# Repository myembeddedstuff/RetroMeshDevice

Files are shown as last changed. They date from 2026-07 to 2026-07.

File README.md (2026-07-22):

# RetroMeshDevice 

An off-grid handheld communicator built for the **Meshtastic Build-Off 2026** hardware competition. 

The goal is to build a standalone device that runs Meshtastic natively, using an ESP32-S3 and a custom 12-button T9 physical keypad (driven by an MCP23017 I/O expander).

<p align="center">
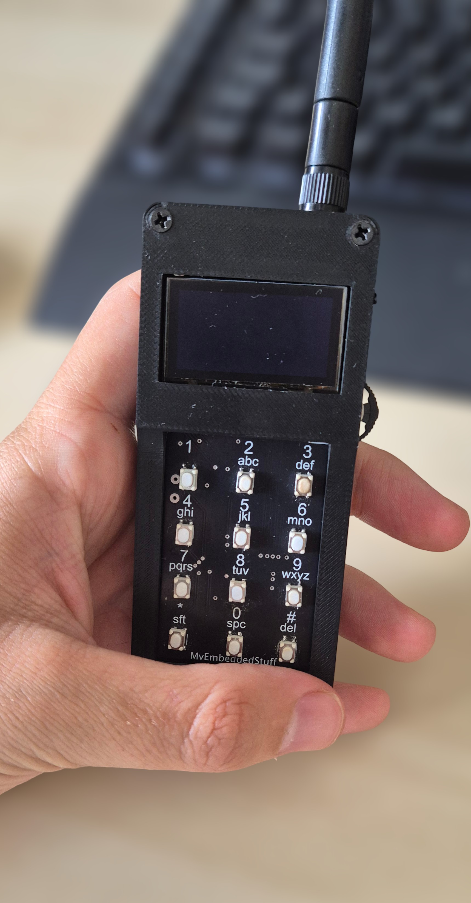
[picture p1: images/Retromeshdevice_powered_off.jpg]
  
</p>

---

## 📖 What this project does

RetroMeshDevice (RMD) is a custom-built, standalone Meshtastic node in a retro phone form factor. Unlike phone-paired setups, it's a self-contained device with its own screen, keypad, battery, and LoRa radio built from scratch around a T9 physical keypad instead of a touchscreen or QWERTY layout.

It's designed as an alternative for people who want a dedicated, pocketable Meshtastic node without depending on a smartphone to configure, send, or read messages
<p align="center">
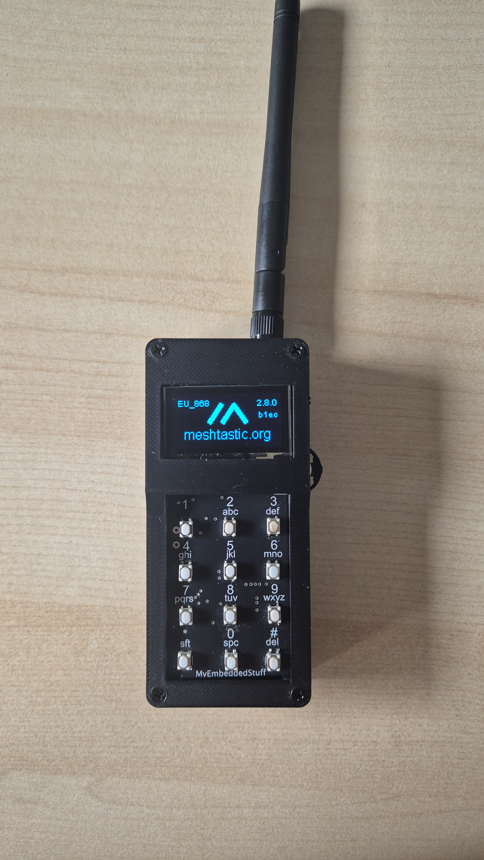
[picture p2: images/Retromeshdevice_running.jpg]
  
</p>

---
I am documenting the entire design and assembly process step-by-step on my blog:
* **Part 1 (Schematic & Design):** [myembeddedstuff.com/meshtastic-build-off-2026-retromeshdevice](https://myembeddedstuff.com/meshtastic-build-off-2026-retromeshdevice)
* **Part 2 (PCB Assembly):** [myembeddedstuff.com/meshtastic-build-off-2026-pcb-assembly](https://myembeddedstuff.com/meshtastic-build-off-2026-pcb-assembly)
* **Part 3 (Firmware Validation & Power Consumption):** [myembeddedstuff.com/meshtastic-build-off-2026-hardware-bring-up](https://myembeddedstuff.com/meshtastic-build-off-2026-hardware-bring-up)

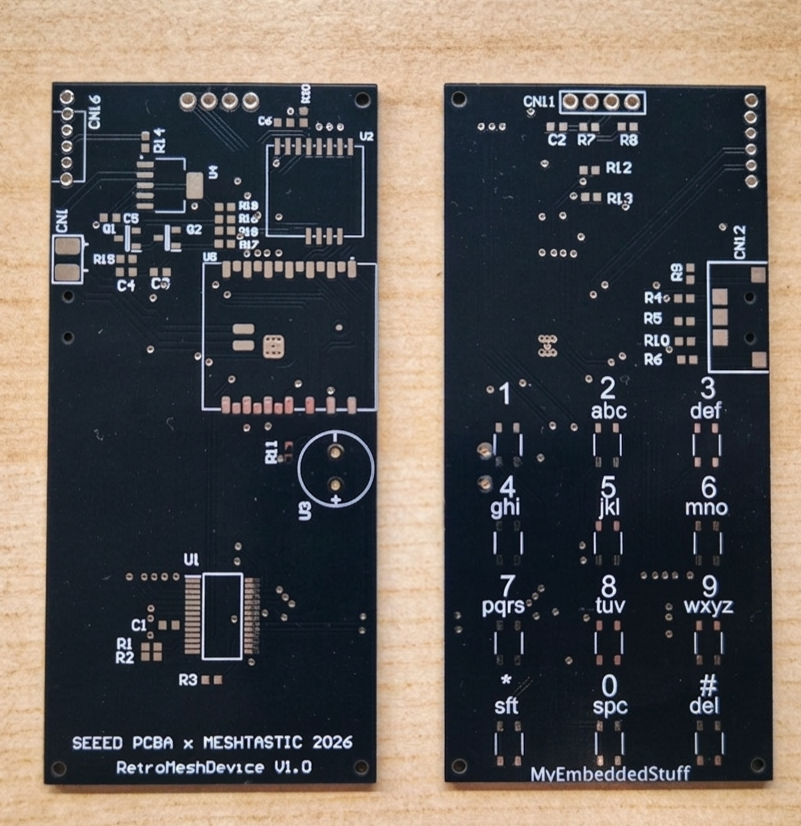
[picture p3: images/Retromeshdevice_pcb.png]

---

### 📂 Repository structure

* **`/case`** — 3D printable case STEP file.
* **`/hardware`** — Schematic diagrams and Bill of Materials (BOM).
* **`/firmware`** — Firmware source code and utilities:
  * **`/Meshtastic`** — Custom Meshtastic variant for this board, ready to compile.
  * **`/Test`** — Standalone hardware self-test firmware for quick board bring-up validation.
  * **`/Bin`** — Precompiled binary (Meshtastic v2.8).
* **`/images`** — Project photos and renders.

---

## 🔗 How it uses Meshtastic

RetroMeshDevice runs a **custom Meshtastic firmware variant** rather than stock Meshtastic, because out-of-the-box Meshtastic firmware doesn't support the MCP23017 I/O expander that drives this board's T9 keypad.

To make this work, I implemented a full MCP23017 keyboard driver for the Meshtastic firmware (interrupt handling, key debounce/multi-tap/long-press logic, I2C device detection) and submitted it upstream:

👉 [meshtastic/firmware PR #11015 — feat: add driver for MCP23017](https://github.com/meshtastic/firmware/pull/11015)

Until this PR is merged into the official Meshtastic repository, you'll need to apply these changes manually (see **Installation** below).

---

## 🚀 Installation & running

1. **Clone the official Meshtastic firmware repo:**
```bash
   git clone https://github.com/meshtastic/firmware.git
   cd firmware
```

2. **Add MCP23017 support:**
   - Check if [PR #11015](https://github.com/meshtastic/firmware/pull/11015) has already been merged into `develop`.
   - **If merged:** skip to step 3.
   - **If not merged yet:** copy over the modified files from that PR into your local clone (`src/detect/ScanI2C.*`, `src/detect/ScanI2CTwoWire.cpp`, `src/input/MCP23017Keyboard.*`, `src/input/cardKbI2cImpl.cpp`, `src/input/kbI2cBase.*`, `src/main.cpp`).

3. **Add the board variant:**
   - Copy the contents of this repo's [`/FW_Meshtastic`](FW_Meshtastic) folder into the corresponding `variants/` folder of your Meshtastic firmware clone.

4. **Build and flash:**
```bash
   pio run -e retroMeshDevice -t upload
```
   This compiles the firmware for the `retroMeshDevice` environment and uploads it directly if the board is connected via USB.

5. **Alternative — use the precompiled binary:**
   - If you don't want to build it yourself, a precompiled binary (Meshtastic v2.8) is available in [`/Bin`](Bin).

6. **Quick hardware test (optional):**
   - Before flashing full Meshtastic firmware, you can validate the board itself using the standalone self-test firmware in [`/FW_TEST`](FW_TEST) — it checks the buzzer, battery ADC, MCP23017/keypad, OLED, and SX1262 radio.

---

### 🏆 Support the project!
This project is officially entered in the contest. If you like the design, please drop a reaction (like a 👍 or ❤️) on the official submission entry here:

👉 [Seeed Studio Build-Off Entry #10](https://github.com/Seeed-Projects/meshtastic-build-off-2026/issues/10)

### 📜 License

This project (hardware design and firmware) is licensed under the **GNU General Public License v3.0** — see [LICENSE](LICENSE) for the full text.

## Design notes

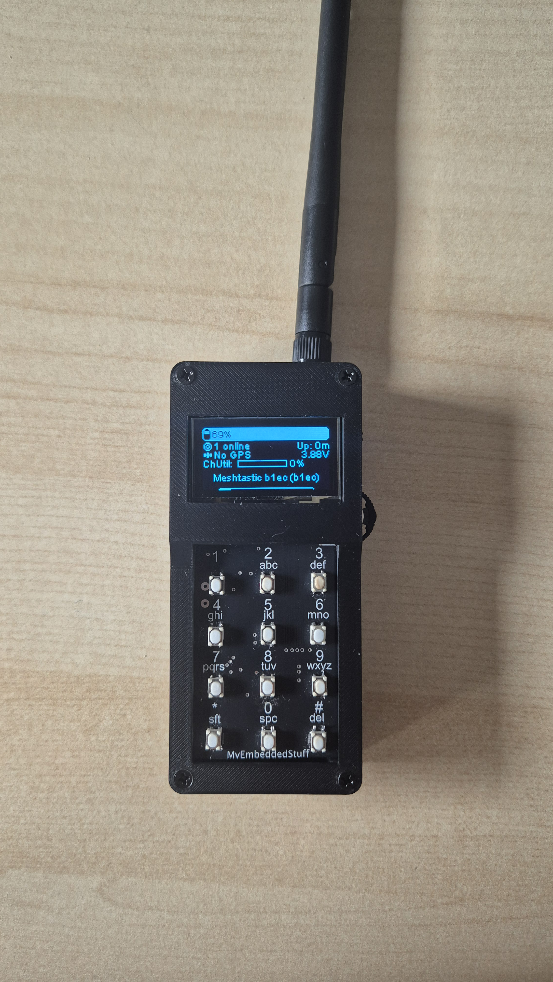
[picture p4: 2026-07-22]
images/Retromeshdevice_running_2.jpg

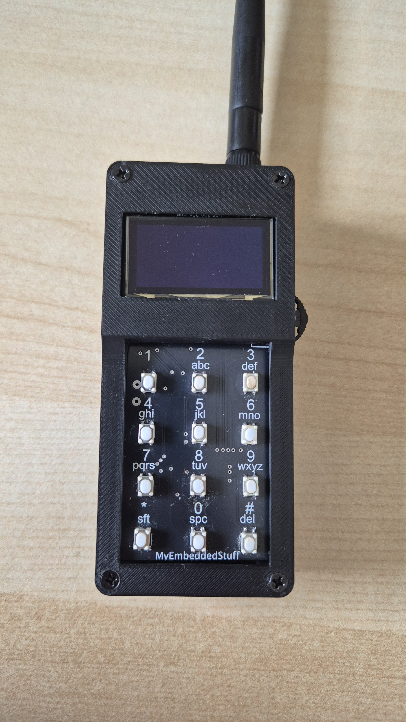
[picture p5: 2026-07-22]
images/Retromeshdevice_powered_off_2.jpg

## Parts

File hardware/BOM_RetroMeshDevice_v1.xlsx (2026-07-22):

Item # | Designator | Quantity | Description | PartNumber | Manufacturer | Footprint
1 | C1, C6 | 2 | 100nF | CL10B104KB8NNNC | Samsung | 0603_CAP
2 | C2 | 1 | 4.7uF | CL10A475KP8NNNC | Samsung | 0603_CAP
3 | C3, C4 | 2 | 1uF | GRM188R71C105KE15D | Murata | 0603_CAP
4 | C5 | 1 | 0.01uF | CC0603KRX7R9BB103 | Yageo | 0603_CAP
5 | CN2, CN3, CN4, CN5, CN6, CN7, CN8, CN9, CN10, CN13, CN14, CN15 | 12 | SKRPABE010 | SKRPABE010 | Alps Alpine | SKRPABE010
6 | CN12 | 1 | MCPL3-AC-V | MCPL3-AC-V | MulticompPro | Rotatory_Encoder
7 | CN16 | 1 | SlideButton | 1825232-1 | TE | 1825232-1
8 | Q1 | 1 | DMG2301L-7* | DMG2301L-7 | Diodes Incorporated | SOT96P240X110-3N
9 | Q2 | 1 | DMG2302UK-7 | DMG2302UK-7 | Diodes Incorporated | SOT96P240X110-3N
10 | R1, R2, R3, R4, R5, R7, R8, R10, R11, R12, R13, R14, R20 | 13 | 10K | RC0603FR-0710KL | Yageo | 0603_R_YAGEO
11 | R6, R9 | 2 | 0Ohm | WR06X000 PTR (https://www.mouser.es/en/ProductDetail/Walsin/WR06X000-PTR) | Walsin | 0603_R_YAGEO
12 | R15, R18 | 2 | 1M | RC0603FR-071ML | Yageo | 0603_R_YAGEO
13 | R16 | 1 | 27K | RC0603FR-0727KL | Yageo | 0603_R_YAGEO
14 | R17 | 1 | 4.7k | RC0603FR-074K7L | Yageo | 0603_R_YAGEO
15 | R19 | 1 | 47K | RC0603FR-0747KL | Yageo | 0603_R_YAGEO
16 | U1 | 1 | MCP23017 | MCP23017-E/SO | Microchip | MCP23017-E/SS
17 | U2 | 1 | WIO_SX1262 | WIO_SX1262 | SeeedStudio | WIO_SX1262
18 | U4 | 1 | TPS79533DCQR | TPS79533DCQR | TI | TPS79533DCQR
19 | U5 | 1 | ESP32_S3_PLUS_XIAO | ESP32_S3_PLUS_XIAO | SeeedStudio | ESP32_S3_PLUS_XIAO
RetroMeshDevice V1.0 | 2026-07-12

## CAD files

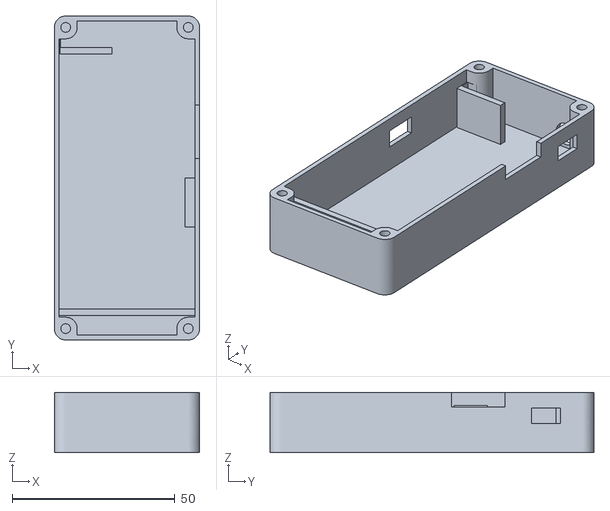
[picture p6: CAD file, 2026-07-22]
case/CASE_RetroMeshdevice_v1.stl
44.6 x 99.4 x 18.5

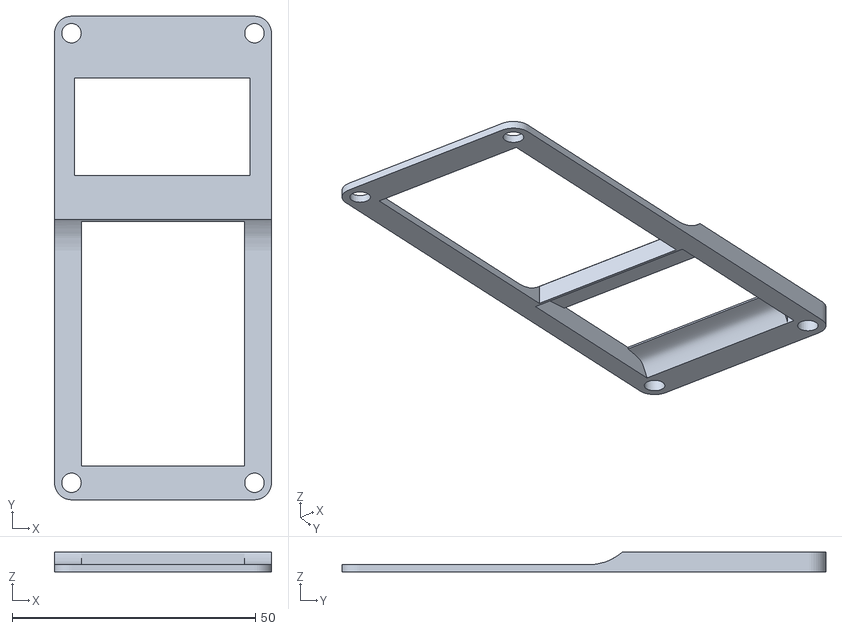
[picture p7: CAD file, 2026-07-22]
case/TAPA_Retromeshdevice_v1.stl
44.6 x 99.4 x 4.10

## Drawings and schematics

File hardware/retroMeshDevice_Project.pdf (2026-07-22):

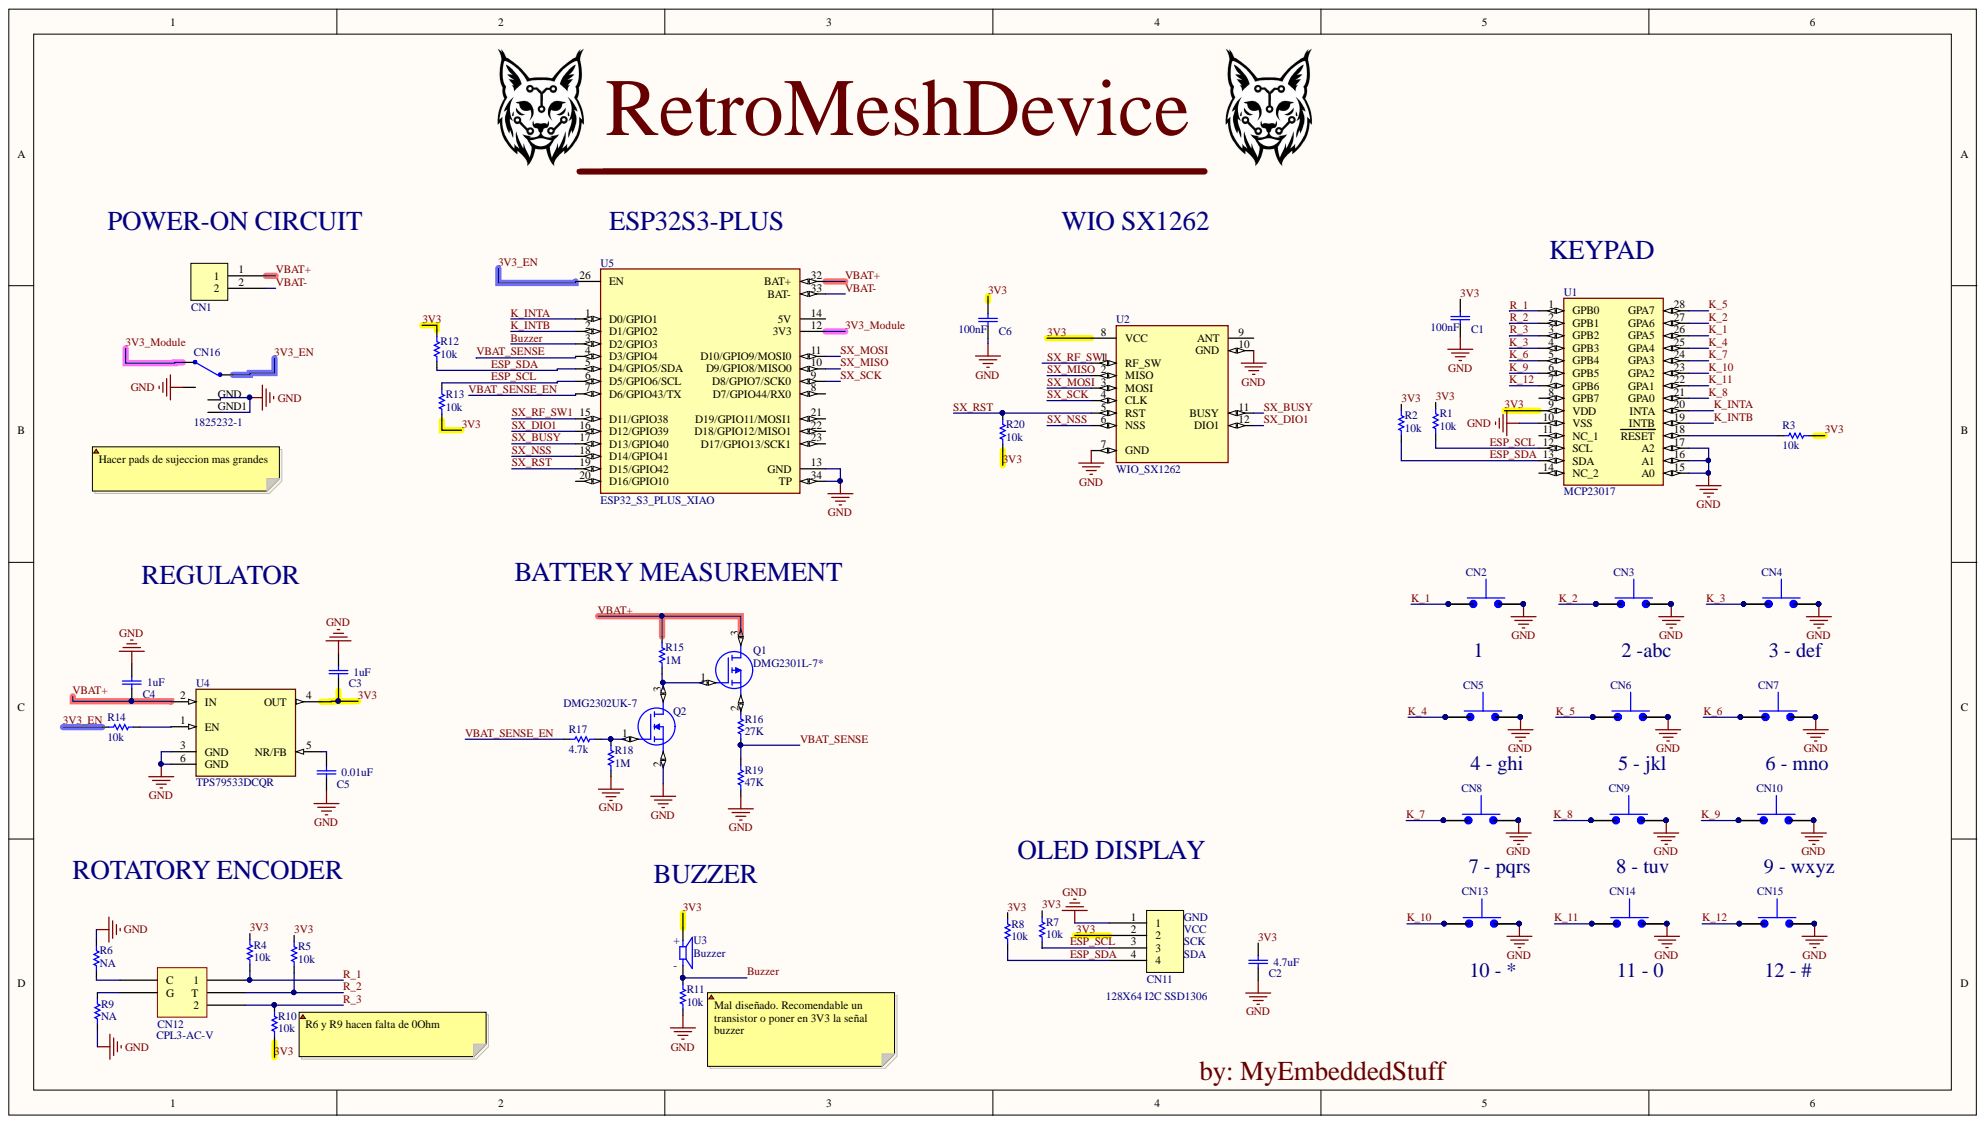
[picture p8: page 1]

Hacer pads de sujeccion mas grandes

Mal diseñado. Recomendable un
transistor o poner en 3V3 la señal
buzzer

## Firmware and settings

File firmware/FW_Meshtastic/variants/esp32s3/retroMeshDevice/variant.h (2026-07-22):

/// =========================================================
// BATTERY
// =========================================================
#define ADC_CTRL 43 
#define ADC_CTRL_ENABLED HIGH
#define BATTERY_PIN 4 
#define ADC_CHANNEL ADC_CHANNEL_3
#define ADC_MULTIPLIER 1.57


/// =========================================================
// COMMS PROTOCOLS
// =========================================================
#define I2C_SDA         5              // GPIO5 / D4
#define I2C_SCL         6              // GPIO6 / D5

/// =========================================================
// OLED SCREEN
// =========================================================
#define USCREEN_SSD1306


// =========================================================
// SX1262 LoRa — WIO SX1262 module via SPI2
// =========================================================
#define USE_SX1262
 
#define LORA_MISO       8              // GPIO8  / D9
#define LORA_SCK        7              // GPIO7  / D8
#define LORA_MOSI       9              // GPIO9  / D10
#define LORA_CS         41             // GPIO41 / D14  (NSS, active-LOW)
#define LORA_RESET      42             // GPIO42 / D15
#define LORA_DIO1       39             // GPIO39 / D12  (IRQ)
#define LORA_DIO2       38             // GPIO38 / D11  (RF switch / RXEN)

#define SX126X_CS               LORA_CS
#define SX126X_DIO1             LORA_DIO1
#define SX126X_BUSY             40     // GPIO40 / D13
#define SX126X_RESET            LORA_RESET
 
// DIO2 drives the RF antenna switch (TX/RX path)
#define SX126X_DIO2_AS_RF_SWITCH
#define SX126X_RXEN             38     // GPIO38 / D11 = SX_RF_SW1
#define SX126X_TXEN             RADIOLIB_NC
 
// TCXO voltage controlled by DIO3 (same as WIO SX1262 reference design)
#define SX126X_DIO3_TCXO_VOLTAGE       1.8


// =========================================================
// BUZZER (GPIO3 / D2)
// =========================================================
//#define PIN_BUZZER      3              // GPIO3 / D2


// =========================================================
// MCP23017 — T9 keypad expander, same I2C bus
// Address: 0x20 (A0=A1=A2=GND)
// INTA → GPIO1 (D0), INTB → GPIO2 (D1)
// =========================================================
#define HAS_KEYBOARD    1
//#define KB_I2C_ADDR     0x20

#define CUSTOM_MCP23017_MAP 

// Port A (Bits 0-7)
#define MCP23017_KEYMAP_0   7
#define MCP23017_KEYMAP_1   10
#define MCP23017_KEYMAP_2   9
#define MCP23017_KEYMAP_3   6
#define MCP23017_KEYMAP_4   3
#define MCP23017_KEYMAP_5   0
#define MCP23017_KEYMAP_6   1
#define MCP23017_KEYMAP_7   4

// Port B (Bits 8-15)
#define MCP23017_KEYMAP_8   12
#define MCP23017_KEYMAP_9   13
#define MCP23017_KEYMAP_10  14
#define MCP23017_KEYMAP_11  2
#define MCP23017_KEYMAP_12  5
#define MCP23017_KEYMAP_13  8
#define MCP23017_KEYMAP_14  11
#define MCP23017_KEYMAP_15  255

#define LONG_PRESS_THRESHOLD 1000
#define MULTI_TAP_THRESHOLD  2000

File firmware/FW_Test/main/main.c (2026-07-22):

/**
 * @file main.c
 * @brief RetroMeshDevice — Hardware Test Suite v2
 *
 * Hardware:
 *  - OLED SH1106 128x64 @ I2C 0x3C   (same bus as the MCP23017)
 *  - MCP23017 @ I2C 0x20             (A0/A1/A2 tied to GND)
 *  - WIO SX1262 @ SPI2
 *  - XIAO ESP32-S3 Plus
 *
 *
 * 
 */

#include <stdio.h>
#include <string.h>
#include <stdarg.h>
#include <inttypes.h>
#include "freertos/FreeRTOS.h"
#include "freertos/task.h"
#include "freertos/queue.h"
#include "driver/gpio.h"
#include "driver/i2c.h"
#include "driver/spi_master.h"
#include "esp_adc/adc_oneshot.h"
#include "esp_log.h"
#include "main.h"
#include "esp_sleep.h"

static const char *TAG = "RMD";

#define VBAT_SENSE_EN GPIO_NUM_43
#define VBAT_SENSE_CHANNEL ADC_CHANNEL_3

static adc_oneshot_unit_handle_t adc_handle;
static adc_cali_handle_t adc_cali_handle = NULL;
static bool do_calibration = false;
float readBatteryVoltage(void);


/* =========================================================
 * MCP23017 registers (BANK = 0)
 * ========================================================= */
#define MCP_IODIRA   0x00
#define MCP_IODIRB   0x01
#define MCP_GPINTENA 0x04
#define MCP_GPINTENB 0x05
#define MCP_DEFVALA  0x06
#define MCP_DEFVALB  0x07
#define MCP_INTCONA  0x08
#define MCP_INTCONB  0x09
#define MCP_IOCON    0x0A
#define MCP_GPPUA    0x0C
#define MCP_GPPUB    0x0D
#define MCP_INTFA    0x0E
#define MCP_INTFB    0x0F
#define MCP_INTCAPA  0x10
#define MCP_INTCAPB  0x11
#define MCP_GPIOA    0x12
#define MCP_GPIOB    0x13
#define IOCON_MIRROR (1 << 6)

/* =========================================================
 * SX1262
 * ========================================================= */
#define SX1262_CMD_GET_STATUS 0xC0
#define SX1262_NOP            0x00

/* =========================================================
 * MCP23017 pin -> key name map
 *
 * Port A (GPA0-7): K_8 K_11 K_10 K_7 K_4 K_1 K_2 K_5
 * Port B (GPB0-7): R_1 R_2  R_3  K_3 K_6 K_9 K_12 NC
 *
 * R_2 = GPB1 -> used as the "next test / skip" button in self-test mode
 * ========================================================= */
static const char *PORT_A_NAME[8] = {
    "K_8", "K_11", "K_10", "K_7", "K_4", "K_1", "K_2", "K_5"
};
static const char *PORT_B_NAME[8] = {
    "R_1", "R_2", "R_3", "K_3", "K_6", "K_9", "K_12", "NC"
};

/* Ordered list of ALL keys for the keypad-walk test (NC excluded) */
typedef struct { const char *name; uint8_t port; uint8_t bit; } KeyDef;
static const KeyDef ALL_KEYS[] = {
    {"K_1",  0, 5}, {"K_2",  0, 6}, {"K_3",  1, 3},
    {"K_4",  0, 4}, {"K_5",  0, 7}, {"K_6",  1, 4},
    {"K_7",  0, 3}, {"K_8",  0, 0}, {"K_9",  1, 5},
    {"K_10", 0, 2}, {"K_11", 0, 1}, {"K_12", 1, 6},
    {"R_1",  1, 0}, {"R_2",  1, 1}, {"R_3",  1, 2},
};
#define N_KEYS (sizeof(ALL_KEYS) / sizeof(ALL_KEYS[0]))
#define R2_PORT  1
#define R2_BIT   1

/* =========================================================
 * ISR queues
 * ========================================================= */
static QueueHandle_t inta_queue = NULL;
static QueueHandle_t intb_queue = NULL;

static void IRAM_ATTR isr_inta(void *arg) {
    uint32_t v = 0;
    xQueueSendFromISR(inta_queue, &v, NULL);
}
static void IRAM_ATTR isr_intb(void *arg) {
    uint32_t v = 0;
    xQueueSendFromISR(intb_queue, &v, NULL);
}

/* =========================================================
 * SPI handle
 * ========================================================= */
static spi_device_handle_t sx_spi = NULL;

/* =========================================================
 * ╔══════════════════════════════════════╗
 * ║         SH1106 OLED DRIVER           ║
 * ║  128x64, I2C, no external library    ║
 * ╚══════════════════════════════════════╝
 *
 * Framebuffer: 128x64 / 8 = 1024 bytes
 * Font: built-in 5x7, 6px wide including spacing
 * ========================================================= */
#define OLED_ADDR      0x3C
#define OLED_W         128
#define OLED_H         64
#define OLED_PAGES     8    /* 64 / 8 */

static uint8_t oled_fb[OLED_PAGES][OLED_W];  /* framebuffer */

/* 5x7 ASCII font (printable chars 0x20-0x7E) */
static const uint8_t FONT5X7[][5] = {
    {0x00,0x00,0x00,0x00,0x00}, /* ' ' */
    {0x00,0x00,0x5F,0x00,0x00}, /* '!' */
    {0x00,0x07,0x00,0x07,0x00}, /* '"' */
    {0x14,0x7F,0x14,0x7F,0x14}, /* '#' */
    {0x24,0x2A,0x7F,0x2A,0x12}, /* '$' */
    {0x23,0x13,0x08,0x64,0x62}, /* '%' */
    {0x36,0x49,0x55,0x22,0x50}, /* '&' */
    {0x00,0x05,0x03,0x00,0x00}, /* ''' */
    {0x00,0x1C,0x22,0x41,0x00}, /* '(' */
    {0x00,0x41,0x22,0x1C,0x00}, /* ')' */
    {0x08,0x2A,0x1C,0x2A,0x08}, /* '*' */
    {0x08,0x08,0x3E,0x08,0x08}, /* '+' */
    {0x00,0x50,0x30,0x00,0x00}, /* ',' */
    {0x08,0x08,0x08,0x08,0x08}, /* '-' */
    {0x00,0x60,0x60,0x00,0x00}, /* '.' */
    {0x20,0x10,0x08,0x04,0x02}, /* '/' */
    {0x3E,0x51,0x49,0x45,0x3E}, /* '0' */
    {0x00,0x42,0x7F,0x40,0x00}, /* '1' */
    {0x42,0x61,0x51,0x49,0x46}, /* '2' */
    {0x21,0x41,0x45,0x4B,0x31}, /* '3' */
    {0x18,0x14,0x12,0x7F,0x10}, /* '4' */
    {0x27,0x45,0x45,0x45,0x39}, /* '5' */
    {0x3C,0x4A,0x49,0x49,0x30}, /* '6' */
    {0x01,0x71,0x09,0x05,0x03}, /* '7' */
    {0x36,0x49,0x49,0x49,0x36}, /* '8' */
    {0x06,0x49,0x49,0x29,0x1E}, /* '9' */
    {0x00,0x36,0x36,0x00,0x00}, /* ':' */
    {0x00,0x56,0x36,0x00,0x00}, /* ';' */
    {0x00,0x08,0x14,0x22,0x41}, /* '<' */
    {0x14,0x14,0x14,0x14,0x14}, /* '=' */
    {0x41,0x22,0x14,0x08,0x00}, /* '>' */
    {0x02,0x01,0x51,0x09,0x06}, /* '?' */
    {0x32,0x49,0x79,0x41,0x3E}, /* '@' */
    {0x7E,0x11,0x11,0x11,0x7E}, /* 'A' */
    {0x7F,0x49,0x49,0x49,0x36}, /* 'B' */
    {0x3E,0x41,0x41,0x41,0x22}, /* 'C' */
    {0x7F,0x41,0x41,0x22,0x1C}, /* 'D' */
    {0x7F,0x49,0x49,0x49,0x41}, /* 'E' */
    {0x7F,0x09,0x09,0x09,0x01}, /* 'F' */
    {0x3E,0x41,0x49,0x49,0x7A}, /* 'G' */
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
};

/* Low-level I2C write to the OLED */
static esp_err_t oled_i2c_write(uint8_t ctrl, const uint8_t *data, size_t len)
{
    i2c_cmd_handle_t cmd = i2c_cmd_link_create();
    i2c_master_start(cmd);
    i2c_master_write_byte(cmd, (OLED_ADDR << 1) | I2C_MASTER_WRITE, true);
    i2c_master_write_byte(cmd, ctrl, true);
    i2c_master_write(cmd, (uint8_t *)data, len, true);
    i2c_master_stop(cmd);
    esp_err_t ret = i2c_master_cmd_begin(I2C_PORT, cmd, pdMS_TO_TICKS(50));
    i2c_cmd_link_delete(cmd);
    return ret;
}

static void oled_cmd(uint8_t c)  { oled_i2c_write(0x00, &c, 1); }
static void oled_data(const uint8_t *d, size_t n) { oled_i2c_write(0x40, d, n); }

static void oled_init(void)
{
    vTaskDelay(pdMS_TO_TICKS(100));
    static const uint8_t init_seq[] = {
        0xAE,       /* display off */
        0xD5,0x80,  /* clock divider */
        0xA8,0x3F,  /* mux ratio 64 */
        0xD3,0x00,  /* display offset 0 */
        0x40,       /* start line 0 */
        0x8D,0x14,  /* charge pump on */
        0x20,0x00,  /* horizontal addressing */
        0xA1,       /* segment remap */
        0xC8,       /* COM scan direction reversed */
        0xDA,0x12,  /* COM pins config */
        0x81,0xCF,  /* contrast */
        0xD9,0xF1,  /* pre-charge period */
        0xDB,0x40,  /* VCOM deselect level */
        0xA4,       /* resume display from RAM */
        0xA6,       /* normal (not inverted) */
        0xAF,       /* display ON */
    };
    for (int i = 0; i < (int)sizeof(init_seq); i++) oled_cmd(init_seq[i]);
    memset(oled_fb, 0, sizeof(oled_fb));
    printf("[OLED] init OK\n");
}

/* Push the framebuffer to the display */
static void oled_flush(void)
{
    for (int page = 0; page < OLED_PAGES; page++) {
        /* SH1106 RAM starts at column 2 (display is only 128 of 132 columns) */
        oled_cmd(0xB0 + page);
        oled_cmd(0x00);  /* column low nibble  = 0 */
        oled_cmd(0x10);  /* column high nibble = 0 */
        oled_data(oled_fb[page], OLED_W);
    }
}

static void oled_clear(void) { memset(oled_fb, 0, sizeof(oled_fb)); }

/* Draw one character at pixel position (x, page). Returns new x. */
static int oled_putchar(int x, int page, char c)
{
    if (page >= OLED_PAGES || x >= OLED_W) return x;
    if (c < 0x20 || c > 0x7E) c = '?';
    const uint8_t *glyph = FONT5X7[c - 0x20];
    for (int col = 0; col < 5 && (x + col) < OLED_W; col++)
        oled_fb[page][x + col] = glyph[col];
    if (x + 5 < OLED_W) oled_fb[page][x + 5] = 0x00; /* letter spacing */
    return x + 6;
}

/* Draw a string at (x, page). Returns final x. */
static int oled_puts(int x, int page, const char *str)
{
    while (*str) x = oled_putchar(x, page, *str++);
    return x;
}

/* printf-style helper to write one OLED text line (page 0-7) */
static void oled_printf(int page, int x, const char *fmt, ...)
{
    char buf[22]; /* 128 px / 6 px per char ~= 21 chars */
    va_list ap;
    va_start(ap, fmt);
    vsnprintf(buf, sizeof(buf), fmt, ap);
    va_end(ap);
    memset(oled_fb[page] + x, 0, OLED_W - x); /* clear rest of the line first */
    oled_puts(x, page, buf);
}

/* Draw a dotted horizontal separator on a page */
static void oled_hline(int page)
{
    memset(oled_fb[page], 0x08, OLED_W);
}

/* Invert a full page (used to highlight a selection) */
static void oled_invert_page(int page)
{
    for (int x = 0; x < OLED_W; x++)
        oled_fb[page][x] ^= 0xFF;
}

/* =========================================================
 * MCP23017 helpers
 * ========================================================= */
static esp_err_t mcp_write(uint8_t reg, uint8_t val)
{
    uint8_t buf[2] = {reg, val};
    i2c_cmd_handle_t cmd = i2c_cmd_link_create();
    i2c_master_start(cmd);
    i2c_master_write_byte(cmd, (MCP23017_ADDR << 1) | I2C_MASTER_WRITE, true);
    i2c_master_write(cmd, buf, 2, true);
    i2c_master_stop(cmd);
    esp_err_t ret = i2c_master_cmd_begin(I2C_PORT, cmd, pdMS_TO_TICKS(50));
    i2c_cmd_link_delete(cmd);
    return ret;
}

static esp_err_t mcp_read(uint8_t reg, uint8_t *val)
{
    i2c_cmd_handle_t cmd = i2c_cmd_link_create();
    i2c_master_start(cmd);
    i2c_master_write_byte(cmd, (MCP23017_ADDR << 1) | I2C_MASTER_WRITE, true);
    i2c_master_write_byte(cmd, reg, true);
    i2c_master_start(cmd);
    i2c_master_write_byte(cmd, (MCP23017_ADDR << 1) | I2C_MASTER_READ, true);
    i2c_master_read_byte(cmd, val, I2C_MASTER_LAST_NACK);
    i2c_master_stop(cmd);
    esp_err_t ret = i2c_master_cmd_begin(I2C_PORT, cmd, pdMS_TO_TICKS(50));
    i2c_cmd_link_delete(cmd);
    return ret;
}

/* Configure the MCP23017: all inputs, pull-ups on, interrupt-on-change */
static void mcp_setup(void)
{
    mcp_write(MCP_IOCON,    0x00);        /* MIRROR=0: INTA=PortA, INTB=PortB */
    mcp_write(MCP_IODIRA,   0xFF);
    mcp_write(MCP_IODIRB,   0xFF);
    mcp_write(MCP_GPPUA,    0xFF);
    mcp_write(MCP_GPPUB,    0xFF);
    mcp_write(MCP_INTCONA,  0x00);        /* interrupt = compare to previous value */
    mcp_write(MCP_INTCONB,  0x00);
    mcp_write(MCP_GPINTENA, 0xFF);
    mcp_write(MCP_GPINTENB, 0xFF);

    uint8_t dummy;
    mcp_read(MCP_INTCAPA, &dummy);  /* clear any pending interrupt */
    mcp_read(MCP_INTCAPB, &dummy);
}

/* Drain ISR queues and clear MCP23017 interrupt flags */
static void mcp_clear_events(void)
{
    uint32_t v;
    while (xQueueReceive(inta_queue, &v, 0) == pdTRUE) {}
    while (xQueueReceive(intb_queue, &v, 0) == pdTRUE) {}
    uint8_t dummy;
    mcp_read(MCP_INTCAPA, &dummy);
    mcp_read(MCP_INTCAPB, &dummy);
}

/* Block until the given MCP23017 pin reads HIGH again (key released) */
static void wait_for_release(uint8_t port, uint8_t bit)
{
    uint8_t reg = (port == 0) ? MCP_GPIOA : MCP_GPIOB;
    uint8_t val;
    do {
        vTaskDelay(pdMS_TO_TICKS(10));
        mcp_read(reg, &val);
    } while (!(val & (1 << bit)));
}

/* Wait for a specific key to be PRESSED (active-LOW).
 * Returns true once the key is pressed, false on timeout.
 * Pressing R_2 instead aborts early and sets *skipped = true
 * (unless the key being waited for IS R_2 itself). */
static bool wait_for_key(const KeyDef *k, uint32_t timeout_ms, bool *skipped)
{
    if (skipped) *skipped = false;
    mcp_clear_events();
    uint32_t v;
    TickType_t deadline = xTaskGetTickCount() + pdMS_TO_TICKS(timeout_ms);

    while (xTaskGetTickCount() < deadline) {
        bool got_event = (xQueueReceive(inta_queue, &v, pdMS_TO_TICKS(20)) == pdTRUE) ||
                          (xQueueReceive(intb_queue, &v, pdMS_TO_TICKS(1))  == pdTRUE);
        if (!got_event) continue;

        vTaskDelay(pdMS_TO_TICKS(20)); /* debounce */
        while (xQueueReceive(inta_queue, &v, 0) == pdTRUE) {}
        while (xQueueReceive(intb_queue, &v, 0) == pdTRUE) {}

        uint8_t gpioa, gpiob, dummy;
        mcp_read(MCP_GPIOA, &gpioa);
        mcp_read(MCP_GPIOB, &gpiob);
        mcp_read(MCP_INTCAPA, &dummy); /* clear INT flags */
        mcp_read(MCP_INTCAPB, &dummy);

        /* R_2 = skip, unless it's the key we're actually waiting for */
        bool target_is_r2 = (k->port == R2_PORT && k->bit == R2_BIT);
        if (!target_is_r2 && !(gpiob & (1 << R2_BIT))) {
            if (skipped) *skipped = true;
            wait_for_release(R2_PORT, R2_BIT);
            mcp_clear_events();
            return false;
        }

        /* Did the target key go LOW (pressed)? */
        uint8_t gpio_val = (k->port == 0) ? gpioa : gpiob;
        if (!(gpio_val & (1 << k->bit))) {
            vTaskDelay(pdMS_TO_TICKS(50));
            wait_for_release(k->port, k->bit);
            mcp_clear_events();
            return true;
        }
    }
    return false; /* timeout */
}

/* =========================================================
 * OLED helpers for the test screens
 * ========================================================= */

/* Header shown at the top of every test screen:
 *   Line 0: "TEST N/M"
 *   Line 1: test name
 *   Line 2: separator
 *   Lines 3-6: status area (cleared, filled in by oled_test_status)
 *   Line 7: "[R2]=Skip" hint */
static void oled_test_header(int n, int total, const char *name)
{
    oled_clear();
    oled_printf(0, 0, "TEST %d/%d", n, total);
    oled_printf(1, 0, "%.21s", name);
    oled_hline(2);
    oled_printf(7, 0, "[R2]=Skip");
    oled_flush();
}

typedef enum { STATUS_RUNNING, STATUS_OK, STATUS_FAIL, STATUS_SKIP } TestStatus;

/* Update the status area (lines 3-5) with the test result */
static void oled_test_status(TestStatus s, const char *detail)
{
    oled_printf(3, 0, "%-21s", "");
    oled_printf(4, 0, "%-21s", "");
    oled_printf(5, 0, "%-21s", "");
    switch (s) {
        case STATUS_RUNNING: oled_printf(3, 0, ">> Running..."); break;
        case STATUS_OK:      oled_printf(3, 0, ">> OK  :)");     break;
        case STATUS_FAIL:    oled_printf(3, 0, ">> FAIL :(");    break;
        case STATUS_SKIP:    oled_printf(3, 0, ">> Skipped");    break;
    }
    if (detail && *detail) oled_printf(4, 0, "%.21s", detail);
    oled_flush();
}

/* =========================================================
 * ╔══════════════════════════════════════╗
 * ║        SELF-TEST FUNCTIONS           ║
 * ╚══════════════════════════════════════╝
 * Each test returns true on pass, false on fail.
 * *skipped is set to true if R_2 was pressed to skip it.
 * ========================================================= */

/* ----------------------------------------------------------
 * T0: Keypad walk — ask the user to press every key in turn
 * ---------------------------------------------------------- */
static bool test_keypad_walk(bool *skipped)
{
    *skipped = false;
    int passed = 0;

    for (int i = 0; i < (int)N_KEYS; i++) {
        const KeyDef *k = &ALL_KEYS[i];

        oled_clear();
        oled_printf(0, 0, "KEYPAD WALK %d/%d", i + 1, (int)N_KEYS);
        oled_hline(1);
        oled_printf(3, 0, "Press:");
        oled_printf(4, 16, ">> %s <<", k->name);
        oled_printf(7, 0, "[R2]=Skip all");
        oled_flush();

        printf("[KEYPAD WALK %d/%d] Press %s\n", i + 1, (int)N_KEYS, k->name);

        bool key_skipped = false;
        bool ok = wait_for_key(k, 30000, &key_skipped);

        if (key_skipped) {
            printf("  -> Skipped\n");
            oled_printf(5, 0, "Skipped");
            oled_flush();
            vTaskDelay(pdMS_TO_TICKS(300));
            *skipped = true;
            break; /* skip the remaining keys too */
        } else if (ok) {
            passed++;
            printf("  -> OK\n");
            oled_printf(5, 0, "OK :)");
            oled_flush();
            vTaskDelay(pdMS_TO_TICKS(400));
        } else {
            printf("  -> TIMEOUT\n");
            oled_printf(5, 0, "TIMEOUT");
            oled_flush();
            vTaskDelay(pdMS_TO_TICKS(500));
        }
    }

    if (*skipped) return false;

    char buf[22];
    snprintf(buf, sizeof(buf), "%d/%d passed", passed, (int)N_KEYS);
    oled_clear();
    oled_printf(0, 0, "KEYPAD WALK");
    oled_hline(1);
    oled_printf(3, 0, "%s", buf);
    oled_printf(4, 0, passed == (int)N_KEYS ? "ALL OK :)" : "Some FAILED");
    oled_flush();
    printf("[KEYPAD WALK] Result: %s\n", buf);
    vTaskDelay(pdMS_TO_TICKS(2000));
    return (passed == (int)N_KEYS);
}

/* ----------------------------------------------------------
 * T1: Buzzer
 * ---------------------------------------------------------- */
static bool test_buzzer(bool *skipped)
{
    *skipped = false;
    gpio_set_level(PIN_BUZZER, 1);   /* 1 = OFF (active-LOW buzzer) */
    vTaskDelay(pdMS_TO_TICKS(200));
    gpio_set_level(PIN_BUZZER, 0);   /* 0 = ON */
    printf("[BUZZER] ON for 1s\n");
    vTaskDelay(pdMS_TO_TICKS(1000));
    gpio_set_level(PIN_BUZZER, 1);   /* back OFF */
    printf("[BUZZER] OFF\n");
    return true; /* no automated pass/fail — the user has to hear it */
}

/* ----------------------------------------------------------
 * Battery ADC
 * ---------------------------------------------------------- */
void initBatteryADC(void)
{
    gpio_config_t io_conf = {
        .pin_bit_mask = (1ULL << VBAT_SENSE_EN),
        .mode         = GPIO_MODE_OUTPUT,
    };
    gpio_config(&io_conf);
    gpio_set_level(VBAT_SENSE_EN, 0);

    adc_oneshot_unit_init_cfg_t init_config = { .unit_id = ADC_UNIT_1 };
    ESP_ERROR_CHECK(adc_oneshot_new_unit(&init_config, &adc_handle));

    adc_oneshot_chan_cfg_t config = {
        .bitwidth = ADC_BITWIDTH_12,
        .atten    = ADC_ATTEN_DB_12,
    };
    ESP_ERROR_CHECK(adc_oneshot_config_channel(adc_handle, VBAT_SENSE_CHANNEL, &config));

    adc_cali_curve_fitting_config_t cali_config = {
        .unit_id  = ADC_UNIT_1,
        .chan     = VBAT_SENSE_CHANNEL,
        .atten    = ADC_ATTEN_DB_12,
        .bitwidth = ADC_BITWIDTH_12,
    };
    if (adc_cali_create_scheme_curve_fitting(&cali_config, &adc_cali_handle) == ESP_OK) {
        do_calibration = true;
    }
}

/* Reads the battery voltage through the 27k/47k divider, averaging
 * 16 samples. Returns the voltage already scaled back up to LiPo level. */
float readBatteryVoltage(void)
{
    gpio_set_level(VBAT_SENSE_EN, 1);
    vTaskDelay(pdMS_TO_TICKS(5));

    const int samples = 16;
    int raw, sum = 0;
    for (int i = 0; i < samples; i++) {
        adc_oneshot_read(adc_handle, VBAT_SENSE_CHANNEL, &raw);
        sum += raw;
        vTaskDelay(pdMS_TO_TICKS(2));
    }
    gpio_set_level(VBAT_SENSE_EN, 0);
    raw = sum / samples;

    int voltage_mv;
    if (do_calibration) {
        adc_cali_raw_to_voltage(adc_cali_handle, raw, &voltage_mv);
    } else {
        voltage_mv = (raw * 3300) / 4095;
    }
    float adc_voltage = voltage_mv / 1000.0f;

    /* Divider: 27k / 47k -> scale ADC reading back up to actual battery voltage */
    float battery_voltage = adc_voltage * ((27.0f + 47.0f) / 47.0f);
    return battery_voltage;
}

/* ----------------------------------------------------------
 * T2: VBAT ADC — also prints the measured voltage on the OLED
 * ---------------------------------------------------------- */
static bool test_vbat(bool *skipped, char *result_buf, size_t buf_size)
{
    *skipped = false;
    float vbat = readBatteryVoltage();
    printf("[VBAT] %.2f V\n", vbat);
    snprintf(result_buf, buf_size, "%.2f V", vbat);
    return (vbat > 3.0f && vbat < 4.3f); /* plausible LiPo range */
}
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
void app_main(void)
{
    printf("\n");
    printf("+--------------------------------------------+\n");
    printf("|       RetroMeshDevice -- Boot               |\n");
    printf("|  XIAO ESP32-S3 Plus + SX1262 + MCP23017     |\n");
    printf("|  OLED SH1106 128x64                         |\n");
    printf("+--------------------------------------------+\n\n");
    init_gpio();
    init_i2c();
    init_spi();
    initBatteryADC();
    vTaskDelay(pdMS_TO_TICKS(100));

    /* Bring up the OLED first so the user sees something immediately */
    oled_init();
    oled_clear();
    oled_printf(0, 0, "RetroMeshDevice");
    oled_hline(1);
    oled_printf(3, 0, "Initializing...");
    oled_flush();
    vTaskDelay(pdMS_TO_TICKS(500));

    

    mcp_setup();
    ESP_LOGI(TAG, "MCP23017 configured");


    run_self_tests();


}

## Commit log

2026-07-12 feat: add firmware for initial board testing
2026-07-22 update local files
    [BOM_RetroMeshDevice_v1.xlsx, CASE_RetroMeshdevice_v1.stl, TAPA_Retromeshdevice_v1.stl]
